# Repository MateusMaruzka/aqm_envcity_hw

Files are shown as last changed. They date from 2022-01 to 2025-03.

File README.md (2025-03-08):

# Air Quality Monitoring Board - EnvCity

## Table of Contents
- [Sensors](#sensors)
- [Powering the board](#powering-the-board)
- [Versions](#versions)
- [Contributing](#contributing)

## Introduction
A detailed explanation of your project, its purpose, and what problem it solves.

## Sensors
Your board supports the following sensors:
- 4 electrochemical sensors
- 1 wind speed sensor
- 1 I2C particulate matter sensor
- 1 DHT11/22 sensor

## Powering the board
Your board supports the following energy sources:
- Solar panel
- Battery
- USB-C

## Versions
There's 2 versions, one it's a 2 layer board and the other it's a 4 layer board (This version could easily be made into a 6 layer board and the fab costs on JLCPCB is the same for 4 or 6 layer boards)

## Contributing
If you have any questions, suggestions, or requests, please send an email to mateusroncaglio@alunos.utfpr.edu.br. We welcome contributions to the project!

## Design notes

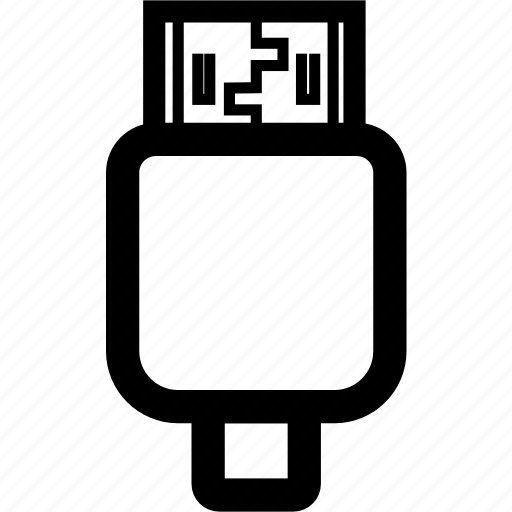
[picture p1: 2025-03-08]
pinout-diagram/img/usb.png

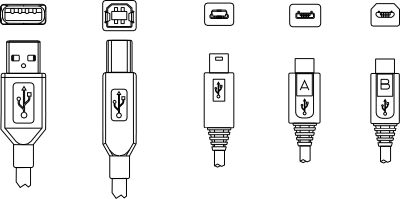
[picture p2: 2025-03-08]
pinout-diagram/img/usbplugs.svg.png

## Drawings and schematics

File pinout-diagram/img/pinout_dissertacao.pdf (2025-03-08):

## GND

## IO21 Data

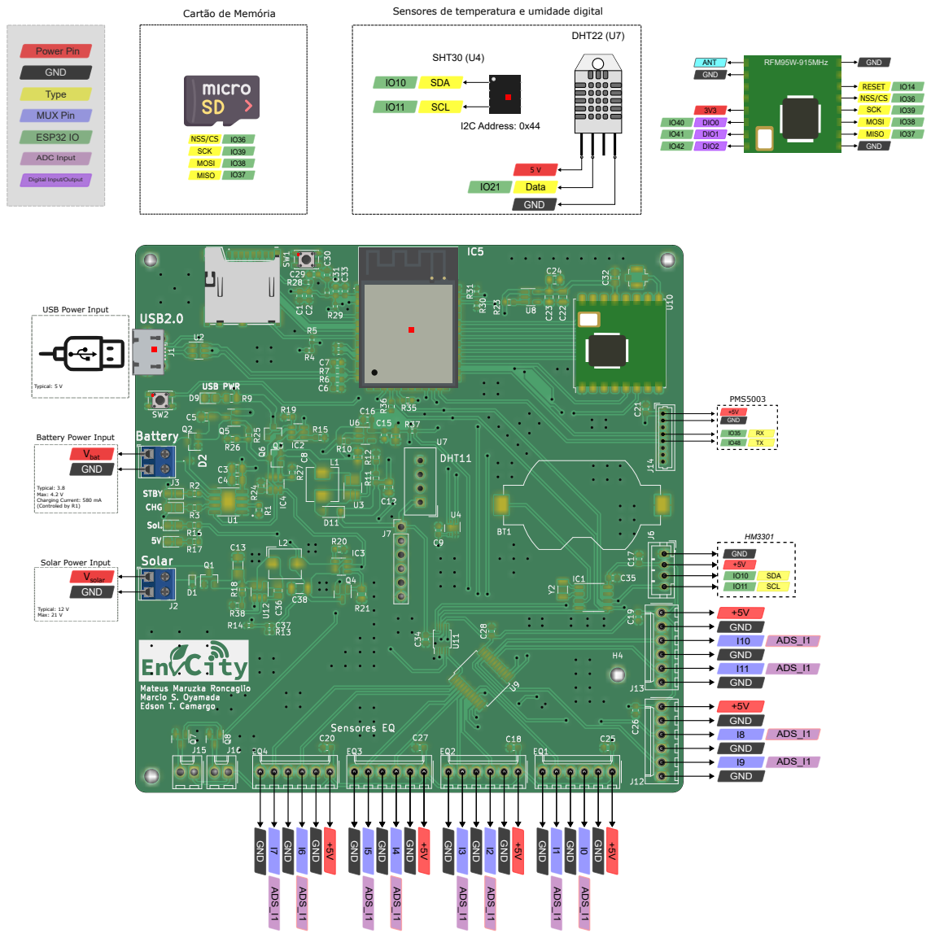
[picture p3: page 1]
GND +5V IO10 IO11; SDA SCL; +5V GND; PMS5003; ADS_I1; I1 ADS_I1; GND; I3 ADS_I1; I10 GND; I8 GND; I5 ADS_I1; I7 ADS_I1; Power Pin; Type; ESP32 IO; MUX Pin; ADC Input; ANT; RFM95W-915MHz; DIO2; DIO1; DIO0; MISO; MOSI; SCK; NSS/CS; RESET; Vbat GND; Vsolar GND; Typical: 12 V Max: 21 V; Typical: 5 V; SHT30 (U4); DHT22 (U7); SDA; I2C Address: 0x44; SCL

Cartão de Memória

Sensores de temperatura e umidade digital

Digital Input/Output

USB Power Input

Battery Power Input

Typical: 3.8
Max: 4.2 V
Charging Current: 580 mA
(Controled by R1)

Solar Power Input

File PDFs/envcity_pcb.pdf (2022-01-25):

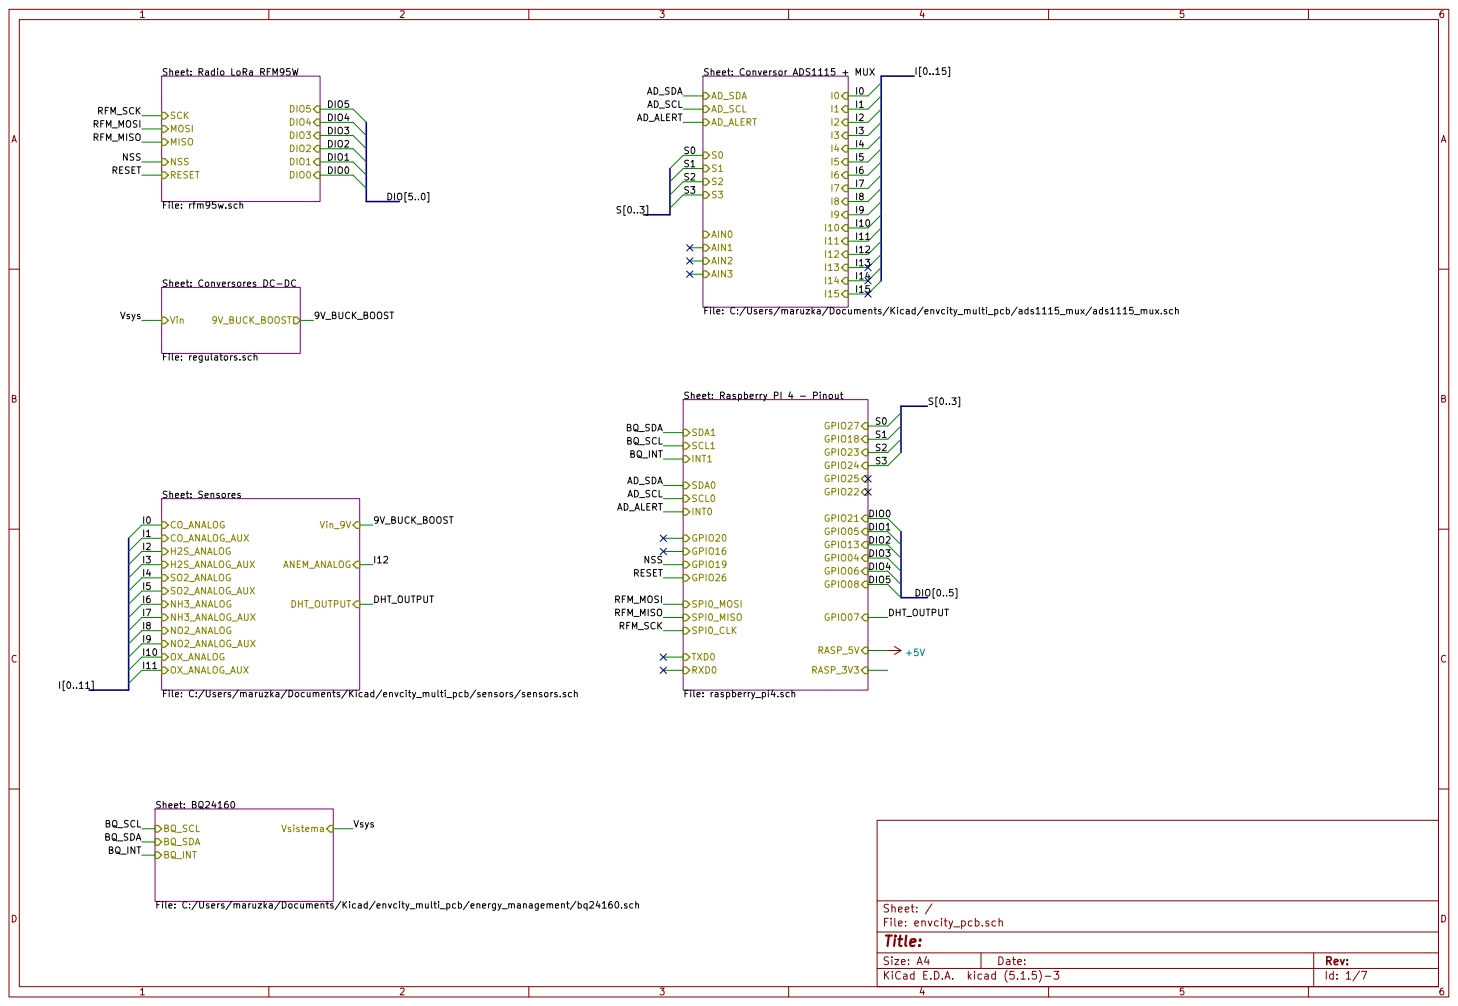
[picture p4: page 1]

AD_SCL AIN0 AIN1 AIN2 AIN3 Sheet: BQ24160 File: C:/Users/maruzka/Documents/Kicad/envcity_multi_pcb/energy_management/bq24160.sch BQ_SCL BQ_SDA

File: C:/Users/maruzka/Documents/Kicad/envcity_multi_pcb/ads1115_mux/ads1115_mux.sch AD_ALERT S0S1S2S3

Sheet: Conversores DC-DC

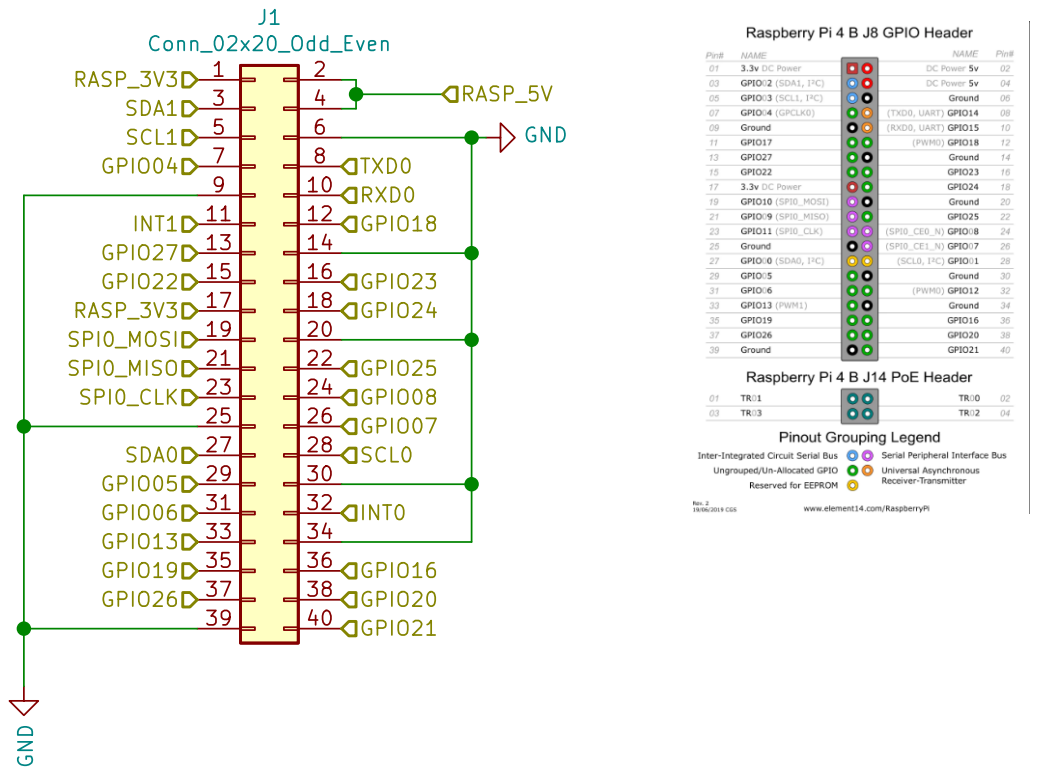
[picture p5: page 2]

Sheet: /Raspberry PI 4 - Pinout/
File: raspberry_pi4.sch
Id: 2/7 Title:

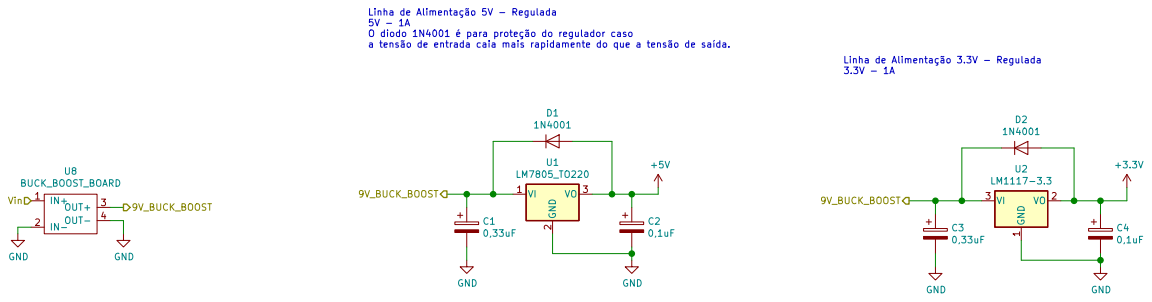
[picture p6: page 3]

Linha de Alimentação 5V - Regulada
5V - 1A O diodo 1N4001 é para proteção do regulador caso

a tensão de entrada caia mais rapidamente do que a tensão de saída.

Linha de Alimentação 3.3V - Regulada

File: regulators.sch Sheet: /Conversores DC-DC/ UNIOESTE/UTFPR

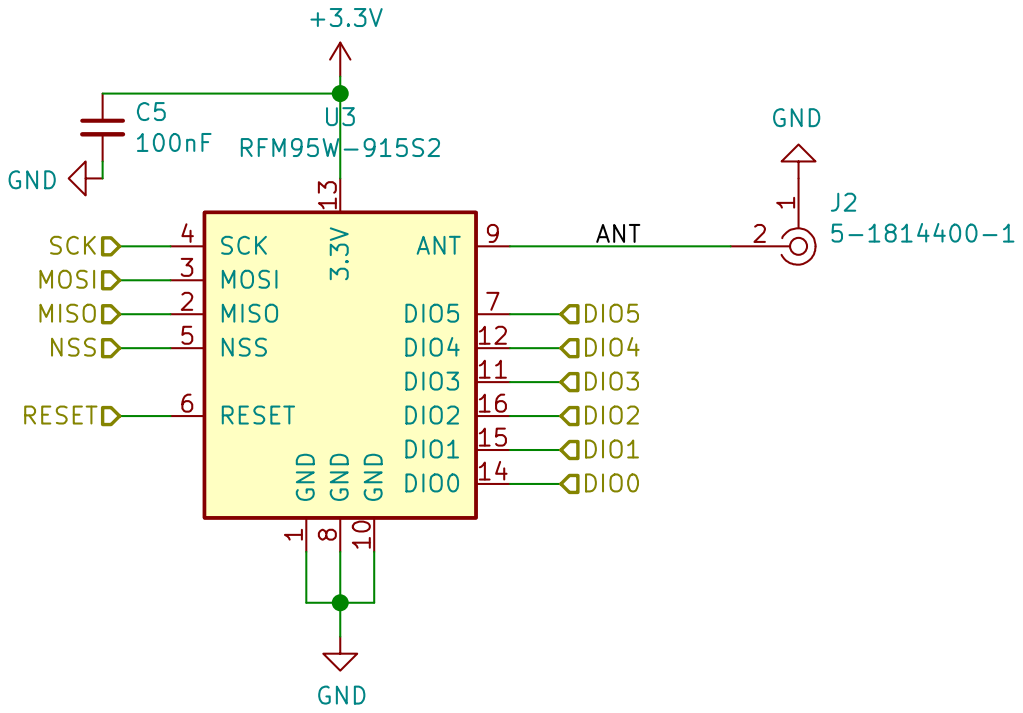
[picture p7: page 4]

8 ANT 9 U3 RFM95W-915S2 RESET DIO5 DIO4 DIO3 NSS MISO MOSI SCK DIO2 DIO1 DIO0 ANT

1 GND 10 DIO3 11 DIO4 12 3.3V 13 DIO0 14 DIO1 15 DIO2 16 MISO 2 MOSI 3 SCK 4 NSS 5 RESET 6 DIO5 7 GND

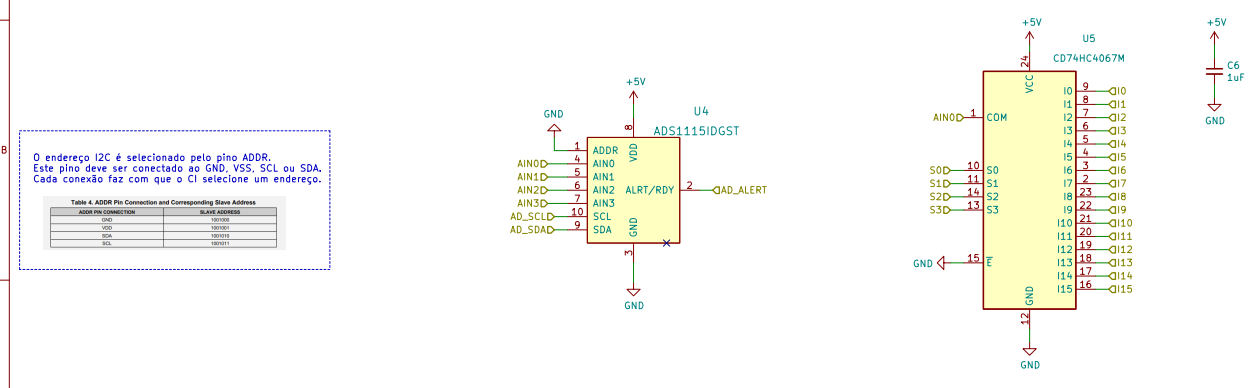
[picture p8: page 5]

I1 AD_SDA O endereço I2C é selecionado pelo pino ADDR.

Este pino deve ser conectado ao GND, VSS, SCL ou SDA.
Cada conexão faz com que o CI selecione um endereço.

File: ads1115_mux.sch Sheet: /Conversor ADS1115 + MUX/ UNIOESTE/UTFPR

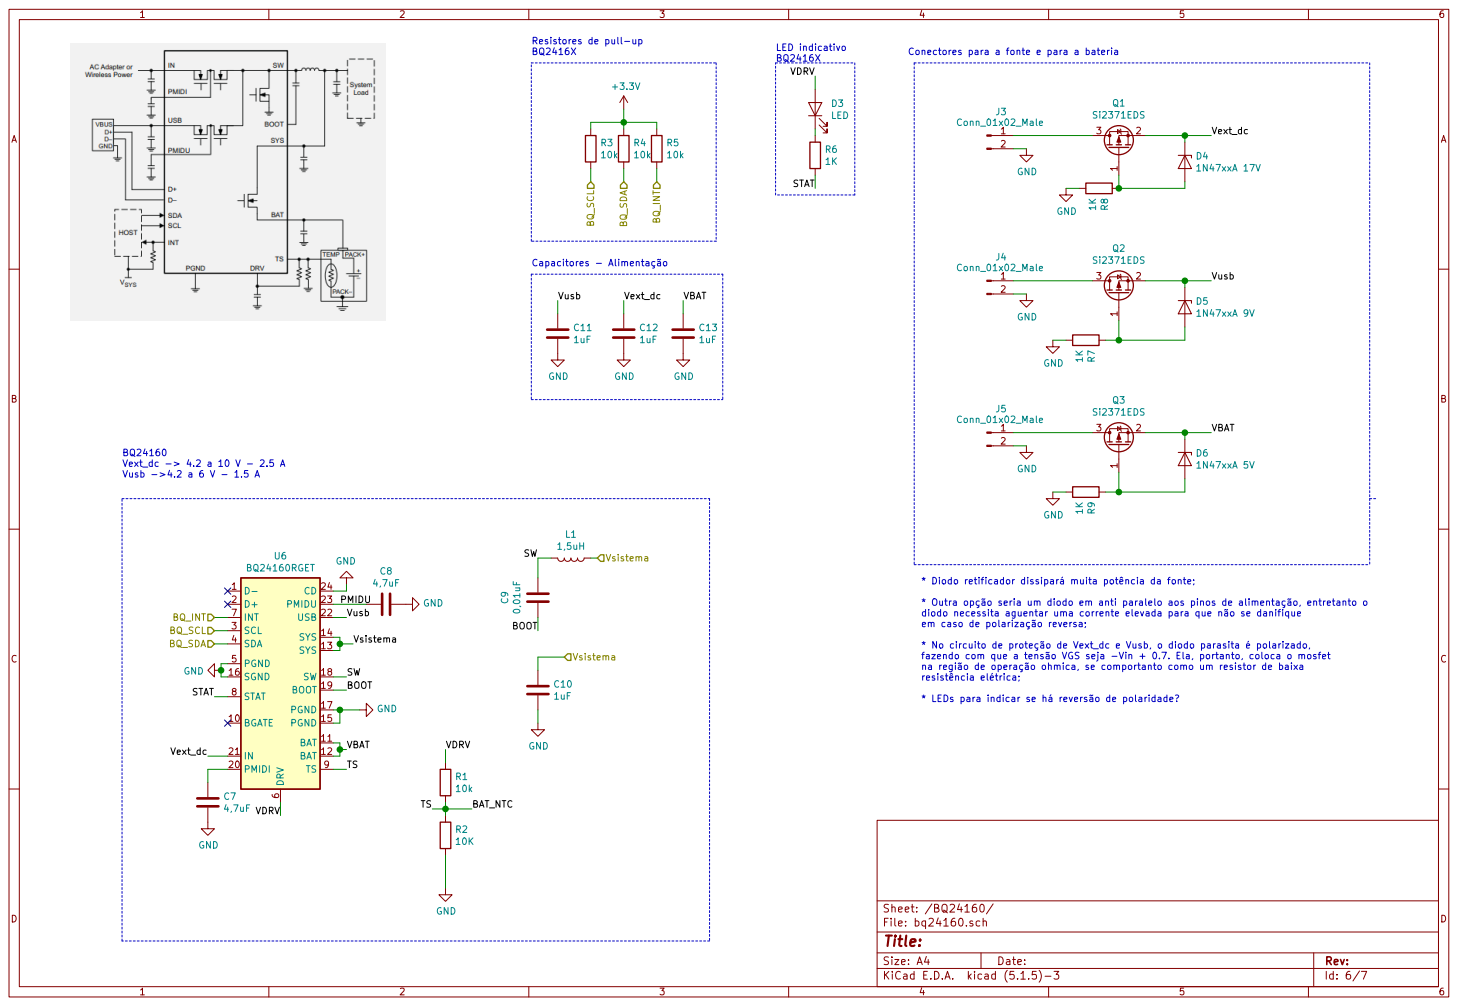
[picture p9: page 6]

Resistores de pull-up BQ2416X

Conectores para a fonte e para a bateria BQ24160 Vext_dc -> 4.2 a 10 V - 2.5 A

* Diodo retificador dissipará muita potência da fonte;

* Outra opção seria um diodo em anti paralelo aos pinos de alimentação, entretanto o
diodo necessita aguentar uma corrente elevada para que não se danifique
em caso de polarização reversa;

* No circuito de proteção de Vext_dc e Vusb, o diodo parasita é polarizado,
fazendo com que a tensão VGS seja -Vin + 0.7. Ela, portanto, coloca o mosfet
na região de operação ohmica, se comportanto como um resistor de baixa resistência elétrica; * LEDs para indicar se há reversão de polaridade?

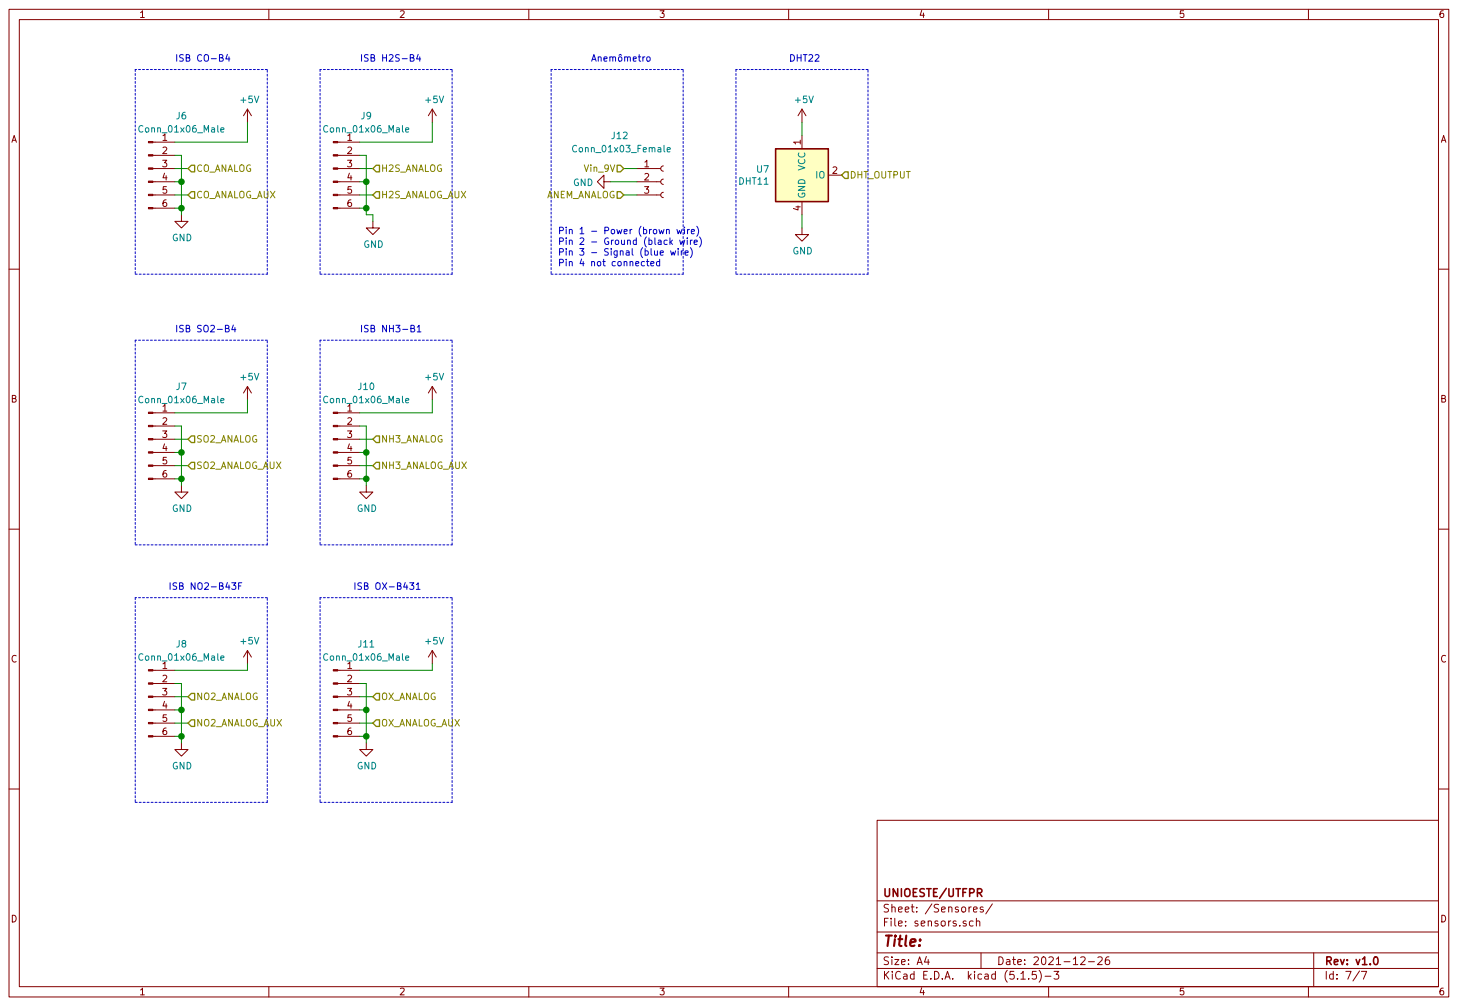
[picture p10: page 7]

Pin 2 - Ground (black wire)
Pin 3 - Signal (blue wire) Pin 4 not connected

Id: 7/7 Title: File: sensors.sch Sheet: /Sensores/ UNIOESTE/UTFPR

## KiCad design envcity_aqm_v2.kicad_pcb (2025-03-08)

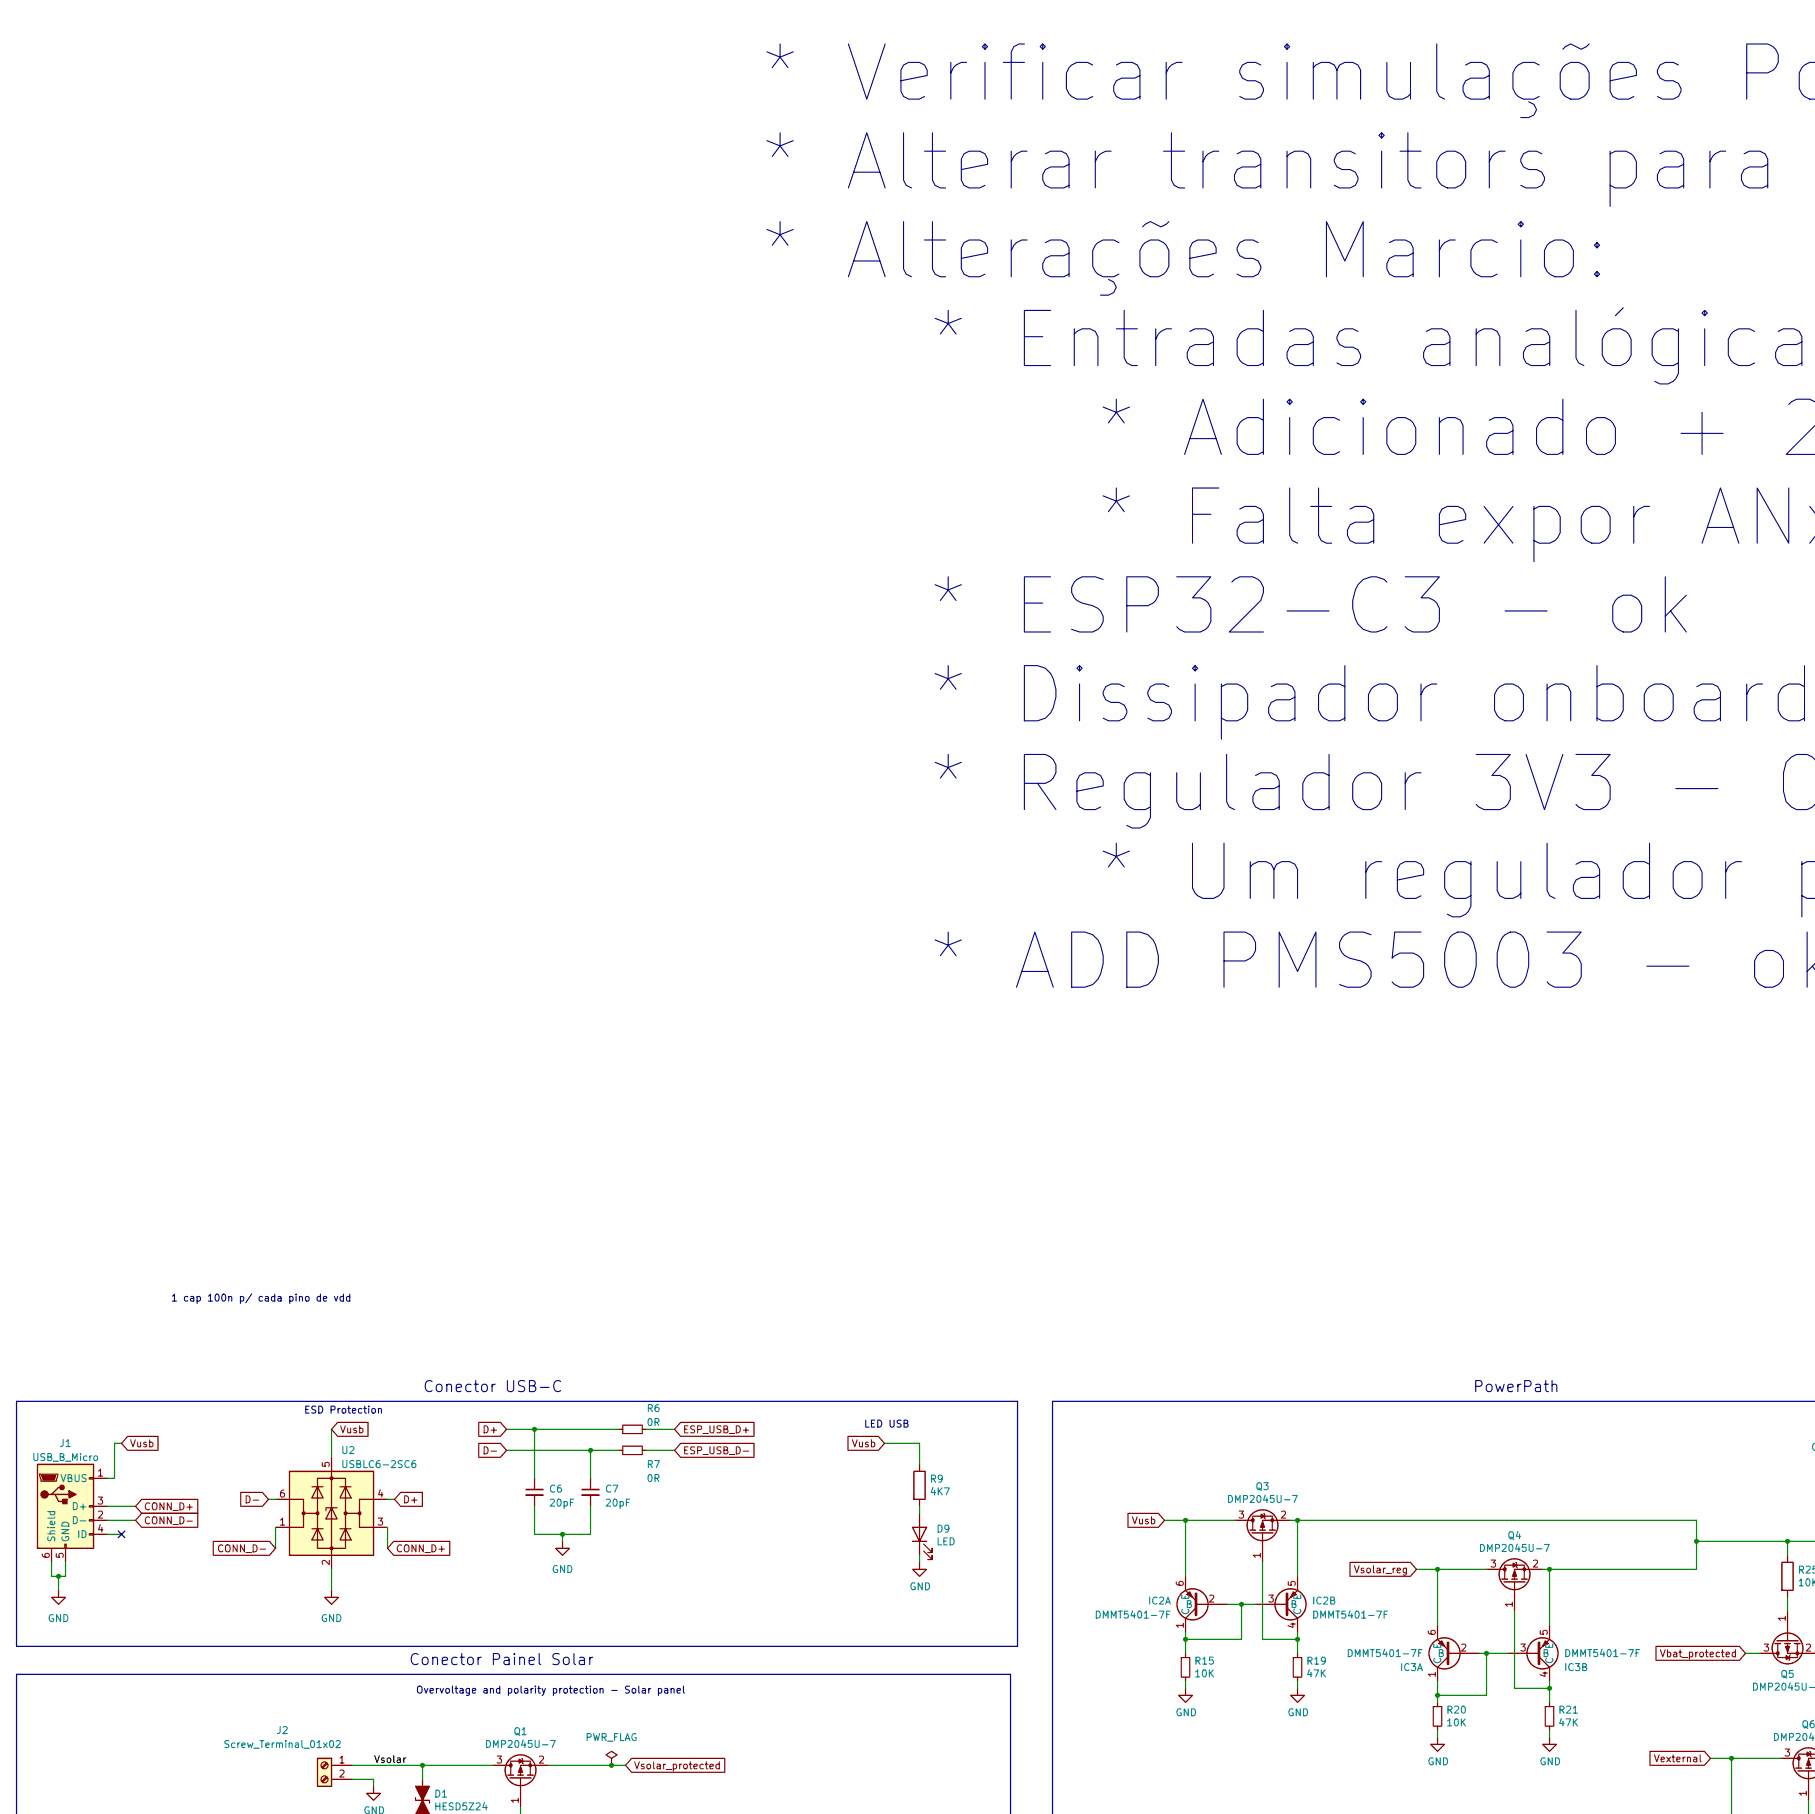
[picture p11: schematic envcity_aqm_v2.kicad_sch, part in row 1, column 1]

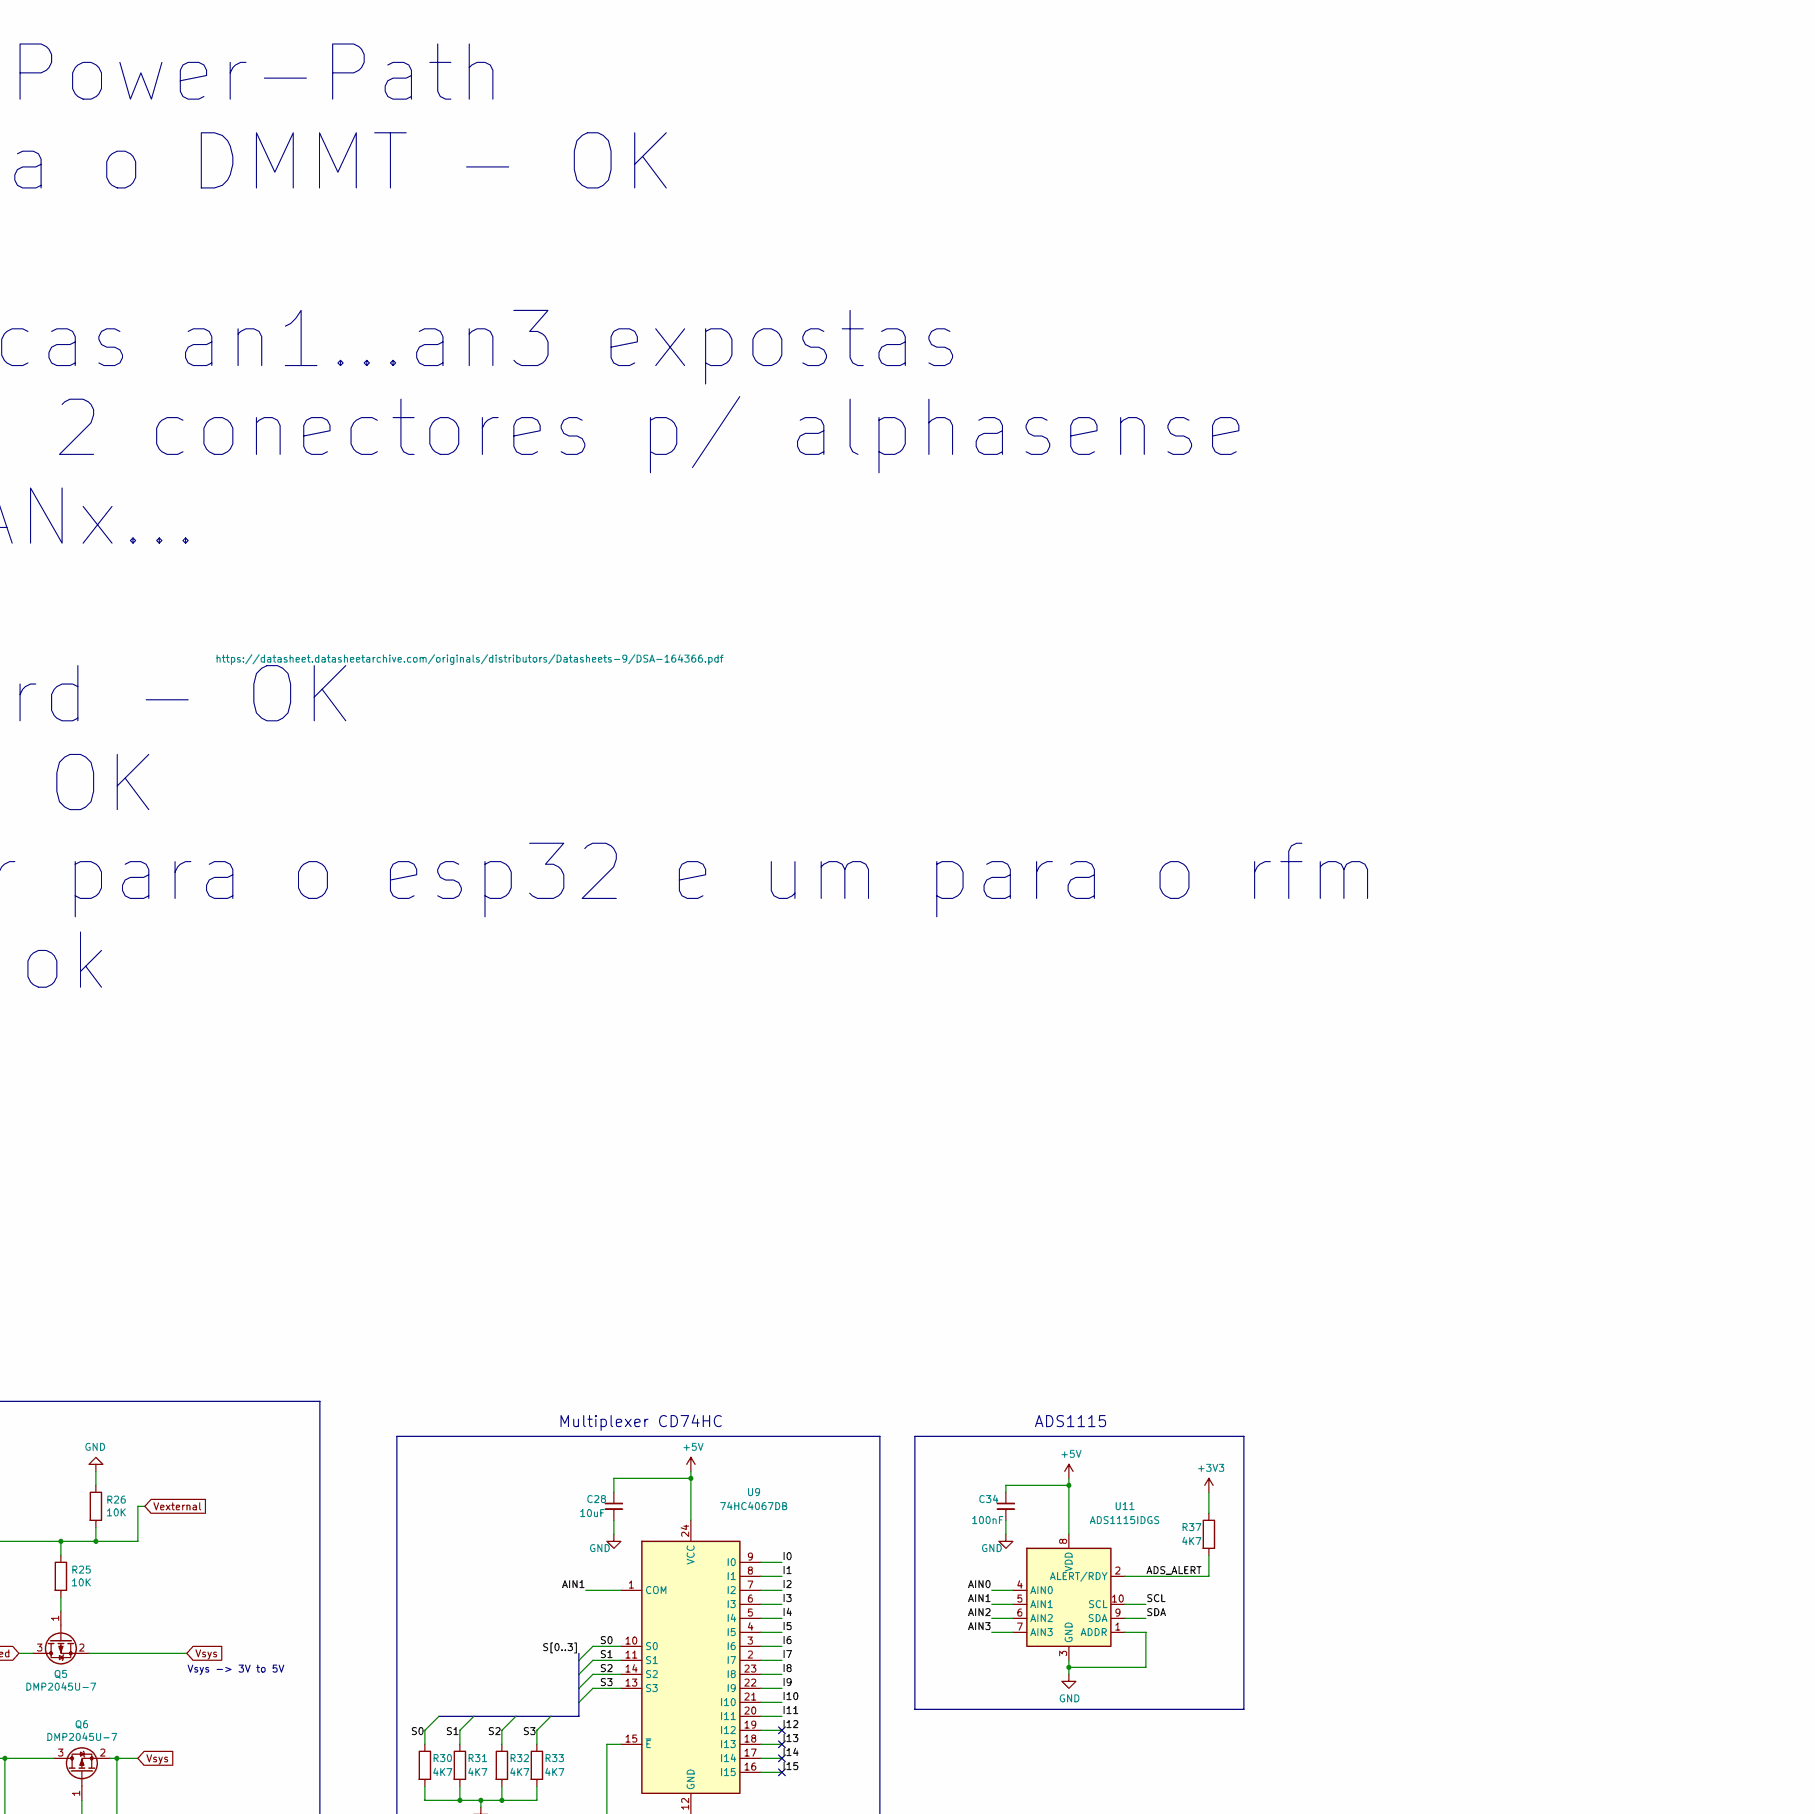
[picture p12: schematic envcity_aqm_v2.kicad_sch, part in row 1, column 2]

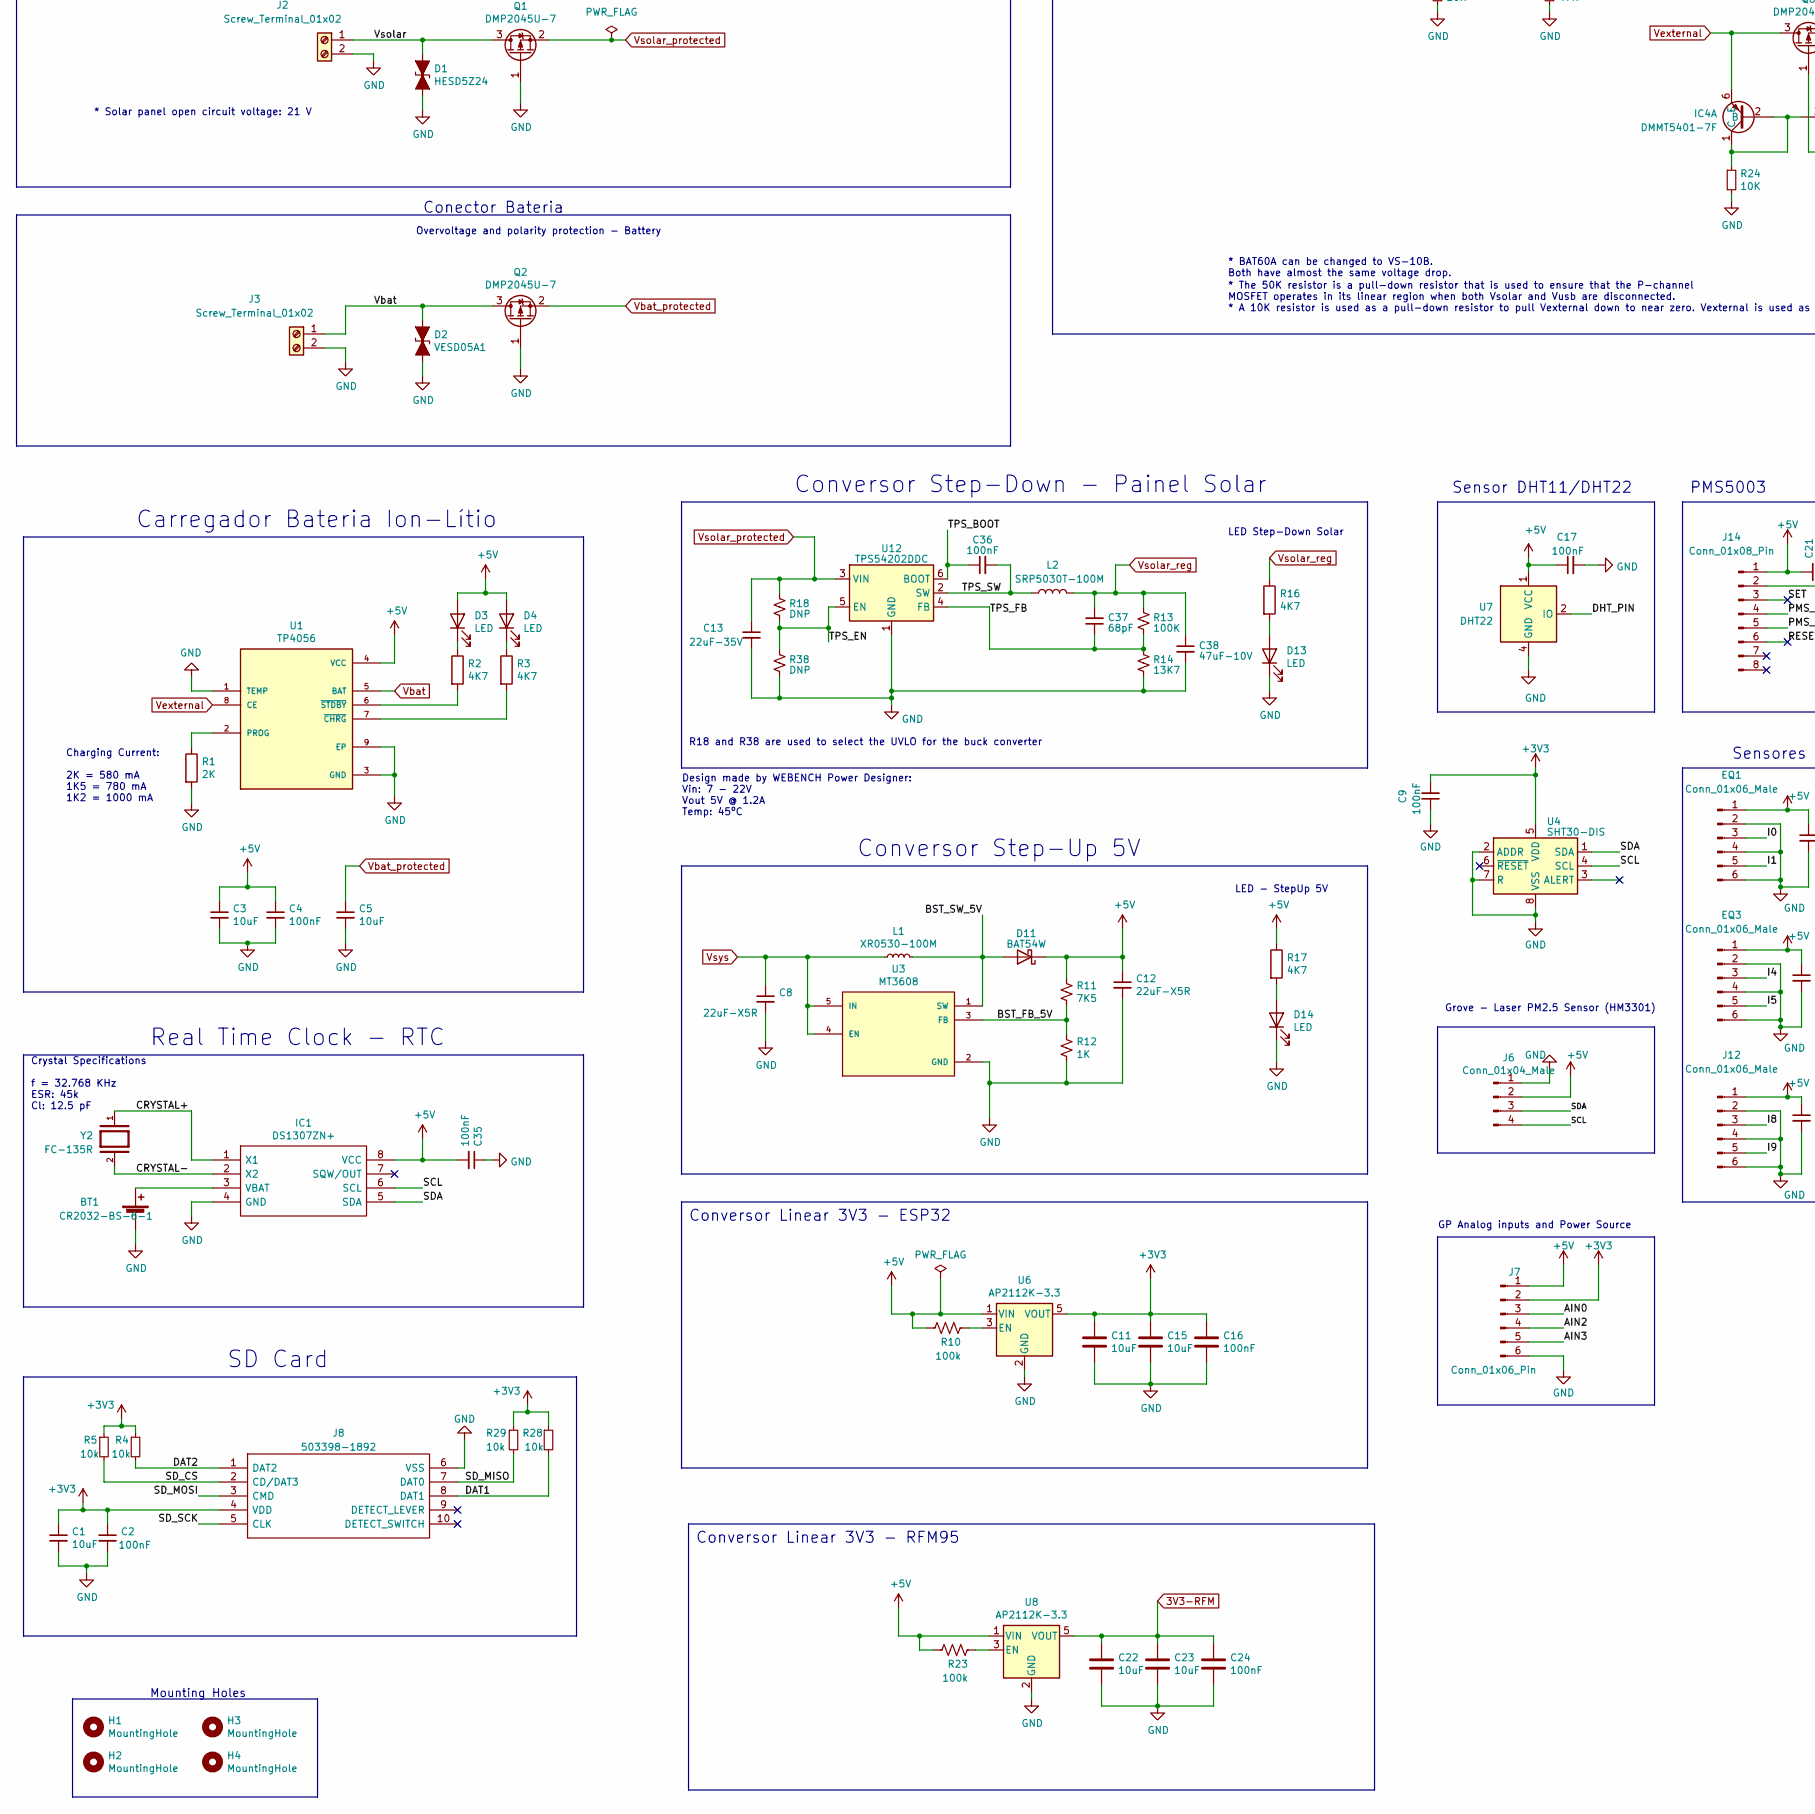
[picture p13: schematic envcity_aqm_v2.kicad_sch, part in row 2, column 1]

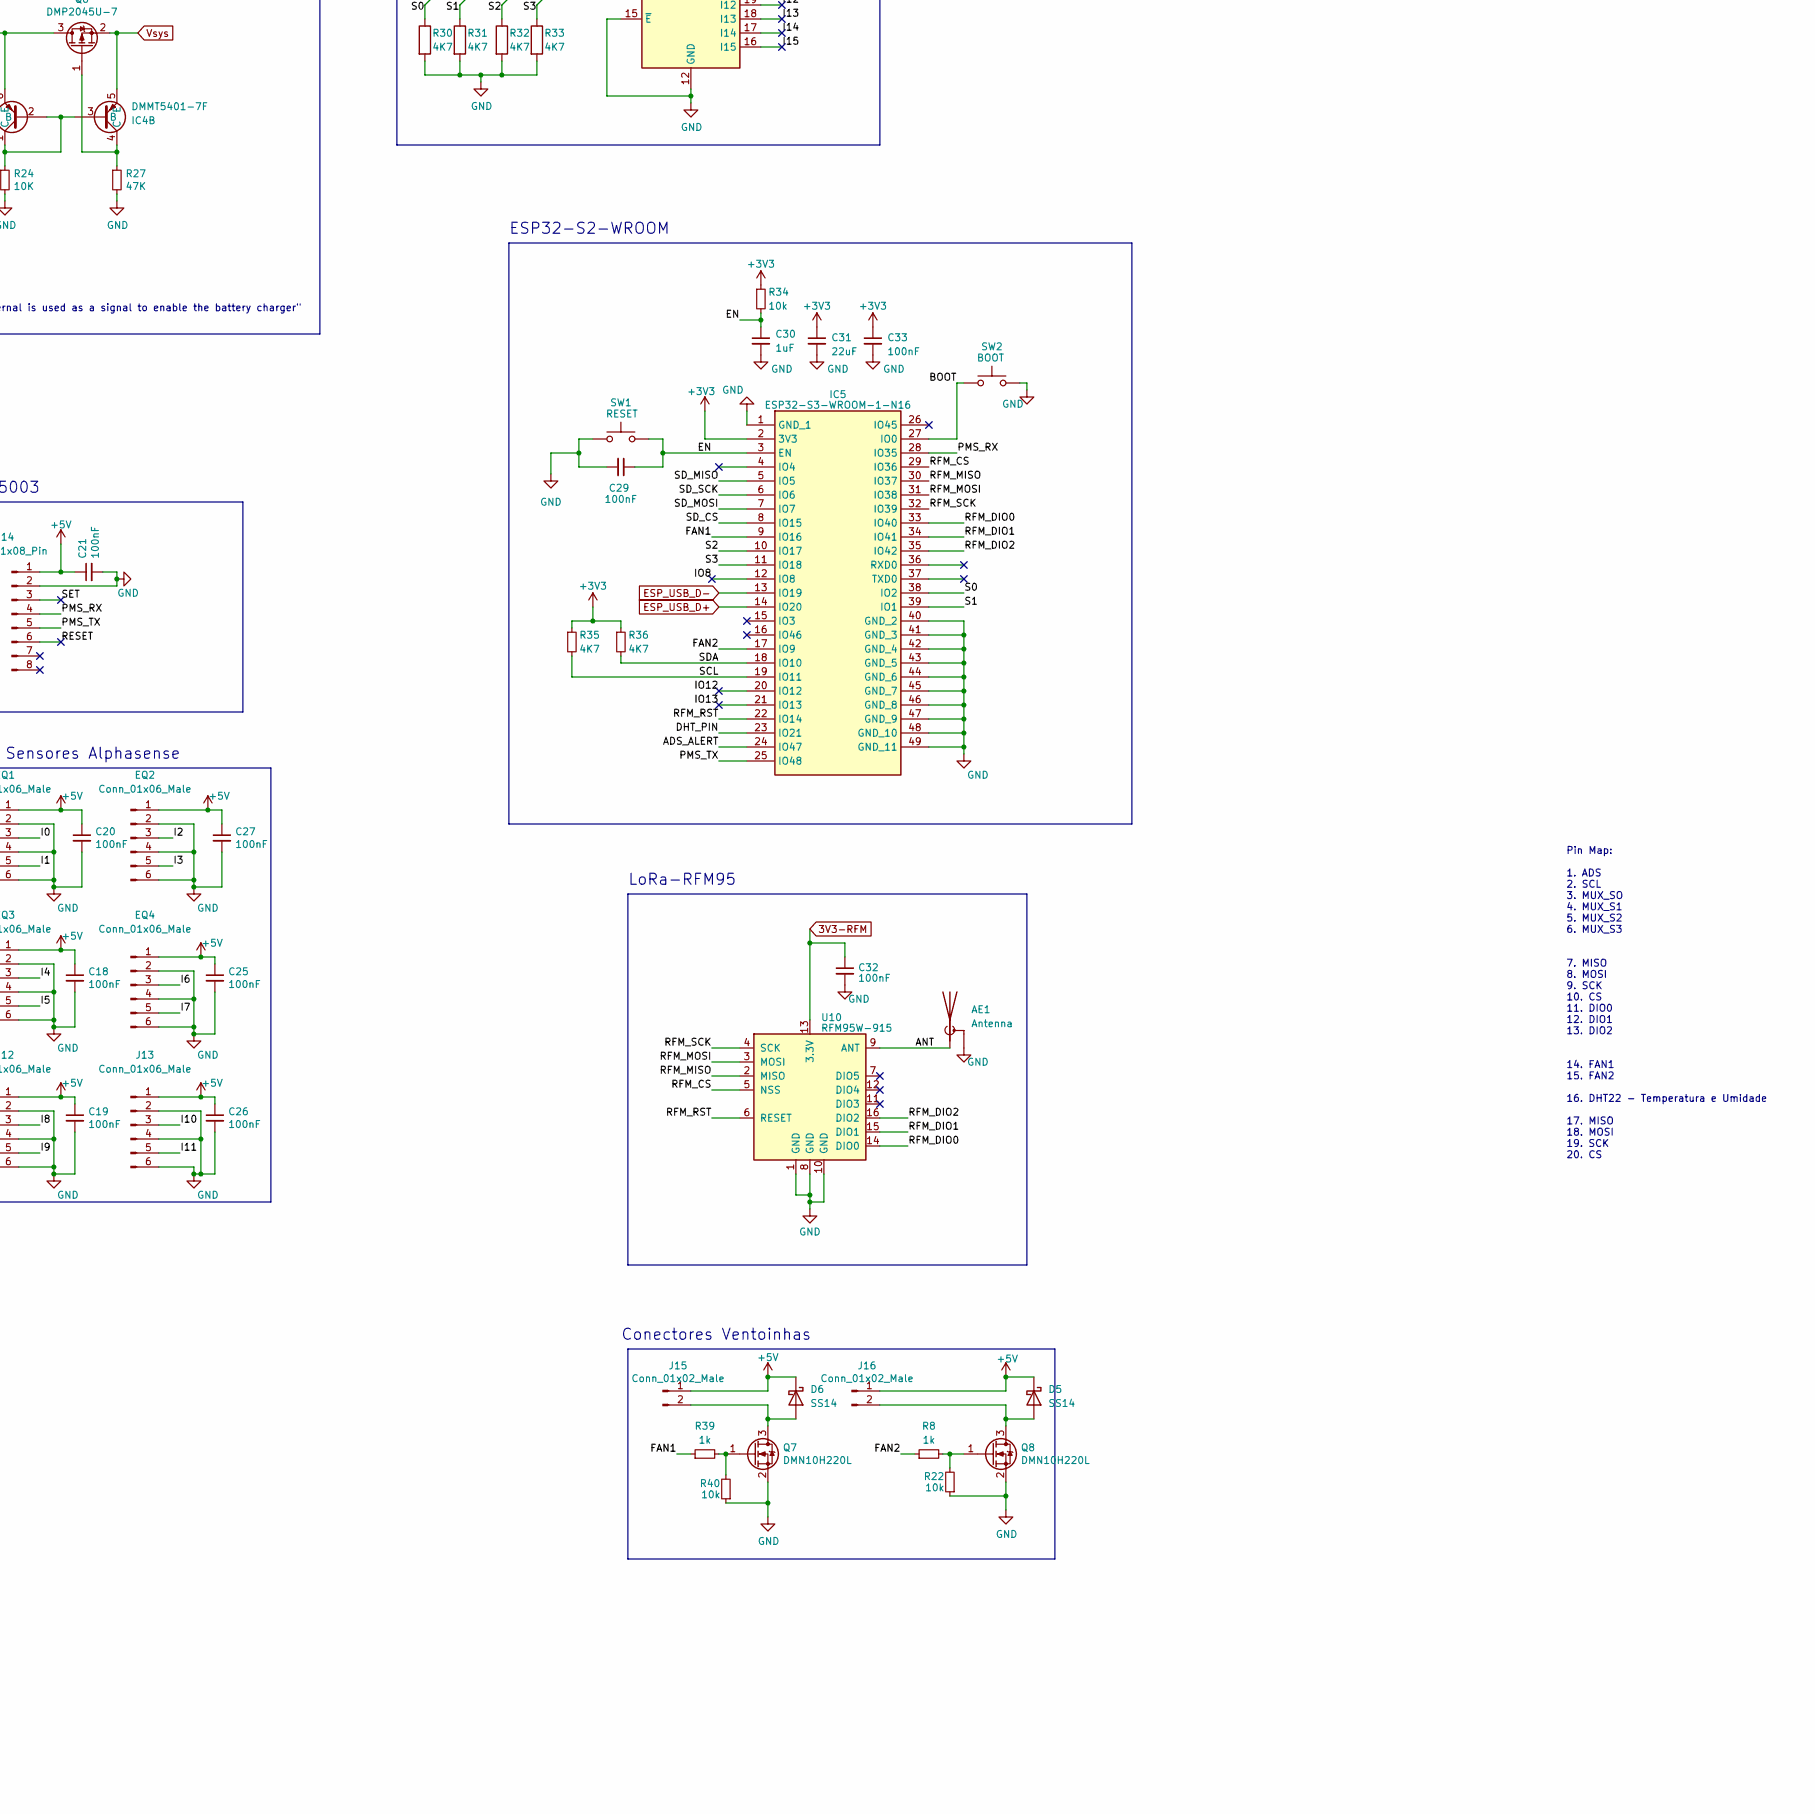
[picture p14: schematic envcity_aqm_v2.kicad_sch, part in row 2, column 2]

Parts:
AE1: Antenna; U.FL_Molex_MCRF_73412-0110_Vertical; LCSC Part # C434806
BT1: CR2032-BS-6-1; BatteryHolder_Keystone_1058_1x2032; LCSC Part # C70377
C1, C15, C28: 10uF; C_0603_1608Metric; LCSC Part # C19702
C2, C9, C16, C17, C18, C19, C20, C21, C25, C26, C27, C29, C33, C34, C35: 100nF; C_0603_1608Metric; LCSC Part # C14663
C3, C5: 10uF; C_0805_2012Metric
C4, C24, C32, C36: 100nF; C_0805_2012Metric; LCSC Part # C14663
C6, C7: 20pF; C_0603_1608Metric
C8, C12: 22uF-X5R; C_0805_2012Metric
C11, C22, C23: 10uF; C_0805_2012Metric; LCSC Part # C19702
C13: 22uF-35V; C_1206_3216Metric; Part # C3216X5R1V226M160AC
C30: 1uF; C_0603_1608Metric
C31: 22uF; C_0603_1608Metric
C37: 68pF; C_0402_1005Metric
C38: 47uF-10V; C_1206_3216Metric; Part # GRM32ER71A476KE15L
D1: HESD5Z24; D_SOD-523; LCSC Part # C3002989
D2: VESD05A1; PESD24VS1ULQZ; LCSC Part # C2844735
D3, D4, D9, D13, D14: LED; LED_0805_2012Metric_Pad1.15x1.40mm_HandSolder
D5, D6: SS14; D_SMA
D11: BAT54W; D_SOD-123; LCSC Part # C915628
EQ1, EQ2, EQ3, EQ4: Conn_01x06_Male; Molex_KK-254_AE-6410-06A_1x06_P2.54mm_Vertical; LCSC Part # C2847672
H1: MountingHole; MountingHole_2.2mm_M2
H2, H3, H4: MountingHole; MountingHole_2.5mm
IC1: DS1307ZN+; SOP-8_3.9x4.9mm_P1.27mm; Mouser Part Number 700-DS1307ZN
IC2, IC3, IC4: DMMT5401-7F; SOT-23-6; Mouser Part Number 621-DMMT5401-7-F
IC5: ESP32-S3-WROOM-1-N16; ESP32S3WROOM1N16; Mouser Part Number 356-ESP32S3WROOM1N16
J1: USB_B_Micro; USB_Micro-B_Molex-105017-0001; JLCPCB Part # C136000
J2, J3: Screw_Terminal_01x02; TerminalBlock_TE_282834-2_1x02_P2.54mm_Horizontal; LCSC Part # C3029316
J6: Conn_01x04_Male; JST_PH_B4B-PH-K_1x04_P2.00mm_Vertical; LCSC Part # C2764213
J7: Conn_01x06_Pin; PinHeader_1x06_P2.54mm_Vertical
J8: 503398-1892; Mouser Part Number 538-503398-1892
J12, J13: Conn_01x06_Male; Molex_KK-254_AE-6410-06A_1x06_P2.54mm_Vertical; LCSC Part # C2847672
J14: Conn_01x08_Pin; Molex_PicoBlade_53047-0810_1x08_P1.25mm_Vertical; JLCPCB Part # C240845
J15: Conn_01x02_Male; Molex_KK-254_AE-6410-02A_1x02_P2.54mm_Vertical; Mfr. Part # 22112022; LCSC Part # C509147
J16: Conn_01x02_Male; Molex_KK-254_AE-6410-02A_1x02_P2.54mm_Vertical; LCSC Part # C509147
L1: XR0530-100M; L_Chilisin_BMRA00050530; LCSC Part # C5307602
L2: SRP5030T-100M; L_Bourns_SRP5030T; Part # SRP5030T-100M; LCSC Part # C189932
Q1, Q2, Q3, Q4, Q5, Q6: DMP2045U-7; SOT-23; LCSC Part # C459541
Q7, Q8: DMN10H220L; SOT-23; LCSC Part # C5122013
R1: 2K; R_0603_1608Metric
R2, R3, R16, R17, R35, R36: 4K7; R_0603_1608Metric; LCSC Part # C23162
R4, R5, R28, R29, R34: 10k; R_0402_1005Metric; LCSC Part # C25744
R6, R7: 0R; R_0603_1608Metric
R8, R39: 1k; R_0805_2012Metric
R9: 4K7; R_0805_2012Metric
R10, R23: 100k; R_0603_1608Metric; LCSC Part # C25804
R11: 7K5; R_0603_1608Metric
R12: 1K; R_0603_1608Metric
R13: 100K; R_0402_1005Metric
R14: 13K7; R_0402_1005Metric
R15, R20, R24, R25, R26: 10K; R_0603_1608Metric; LCSC Part # C25804
R18, R38: DNP; R_0603_1608Metric
R19, R27: 47K; R_0603_1608Metric
R21: 47K; R_0805_2012Metric
R22, R40: 10k; R_0805_2012Metric
R30, R31, R32, R33, R37: 4K7; R_0402_1005Metric; LCSC Part # C25900
SW1: RESET; SW_SPST_PTS810; JLCPCB Part # C221897
SW2: BOOT; SW_SPST_PTS810; JLCPCB Part # C221897
U1: TP4056; SOP127P600X175-9N; LCSC Part # C382139
U2: USBLC6-2SC6; SOT-23-6; LCSC Part # C7519
U3: MT3608; SOT-23-6_Handsoldering; PARTREV 1.0; JLCPCB Part # C84817
U4: SHT30-DIS; Sensirion_DFN-8-1EP_2.5x2.5mm_P0.5mm_EP1.1x1.7mm; JLCPCB Part # C2687423
U6, U8: AP2112K-3.3; SOT-23-5; LCSC Part # C51118
U7: DHT22; Aosong_DHT11_5.5x12.0_P2.54mm
U9: 74HC4067DB; SSOP-24_5.3x8.2mm_P0.65mm; LCSC Part # C97702
U10: RFM95W-915; HOPERF_RFM9XW_SMD; LCSC Part # C2844473
U11: ADS1115IDGS; TSSOP-10_3x3mm_P0.5mm; JLCPCB Part # C37593
U12: TPS54202DDC; SOT-23-6
Y2: FC-135R; Crystal_SMD_3215-2Pin_3.2x1.5mm; JLCPCB Part # C94276

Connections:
3V3-RFM: C22.1, C23.1, C24.1, C32.1, U8.5 (VOUT), U10.13 (3.3V)
+3V3: C1.1, C2.1, C9.2, C11.1, C15.1, C16.1, C31.1, C33.1, IC5.2 (3V3), J7.2, J8.4 (VDD), R4.1, R5.1, R28.1, R29.1, R34.1, R35.1, R36.1, R37.1, U4.5 (VDD), U6.5 (VOUT)
+5V: C3.1, C4.1, C12.1, C17.1, C18.1, C19.1, C20.1, C21.1, C25.1, C26.1, C27.1, C28.1, C34.1, C35.2, D3.2 (A), D4.2 (A), D5.1 (K), D6.1 (K), D11.1 (K), EQ1.1, EQ2.1, EQ3.1, EQ4.1, IC1.8 (VCC), J6.2, J7.1, J12.1, J13.1, J14.1, J15.1, J16.1, R10.1, R11.1, R17.1, R23.1, U1.4 (VCC), U6.1 (VIN), U7.1 (VCC), U8.1 (VIN), U9.24 (VCC), U11.8 (VDD)
/ADS_ALERT: IC5.24 (IO47), R37.2, U11.2 (ALERT/RDY)
/AIN0: J7.3, U11.4 (AIN0)
/AIN1: U9.1 (COM), U11.5 (AIN1)
/AIN2: J7.4, U11.6 (AIN2)
/AIN3: J7.5, U11.7 (AIN3)
/ANT: AE1.1 (A), U10.9 (ANT)
/BOOT: IC5.27 (IO0), SW2.1
/BST_FB_5V: R11.2, R12.1, U3.3 (FB)
/BST_SW_5V: D11.2 (A), L1.2, U3.1 (SW)
/CRYSTAL+: IC1.1 (X1), Y2.1
/CRYSTAL-: IC1.2 (X2), Y2.2
/DAT1: J8.8 (DAT1), R28.2
/DAT2: J8.1 (DAT2), R4.2
/DHT_PIN: IC5.23 (IO21), U7.2 (IO)
/EN: C29.1, C30.1, IC5.3 (EN), R34.2, SW1.2
/FAN1: IC5.9 (IO16), R39.1
/FAN2: IC5.17 (IO9), R8.1
/I0: EQ1.3, U9.9 (I0)
/I1: EQ1.5, U9.8 (I1)
/I2: EQ2.3, U9.7 (I2)
/I3: EQ2.5, U9.6 (I3)
/I4: EQ3.3, U9.5 (I4)
/I5: EQ3.5, U9.4 (I5)
/I6: EQ4.3, U9.3 (I6)
/I7: EQ4.5, U9.2 (I7)
/I8: J12.3, U9.23 (I8)
/I9: J12.5, U9.22 (I9)
/I10: J13.3, U9.21 (I10)
/I11: J13.5, U9.20 (I11)
/I12: U9.19 (I12)
/I13: U9.18 (I13)
/I14: U9.17 (I14)
/I15: U9.16 (I15)
/IO8: IC5.12 (IO8)
/IO12: IC5.20 (IO12)
/IO13: IC5.21 (IO13)
/PMS_RX: IC5.28 (IO35), J14.4
/PMS_TX: IC5.25 (IO48), J14.5
/RESET: J14.6
/RFM_CS: IC5.29 (IO36), U10.5 (NSS)
/RFM_DIO0: IC5.33 (IO40), U10.14 (DIO0)
/RFM_DIO1: IC5.34 (IO41), U10.15 (DIO1)
/RFM_DIO2: IC5.35 (IO42), U10.16 (DIO2)
/RFM_MISO: IC5.30 (IO37), U10.2 (MISO)
/RFM_MOSI: IC5.31 (IO38), U10.3 (MOSI)
/RFM_RST: IC5.22 (IO14), U10.6 (RESET)
/RFM_SCK: IC5.32 (IO39), U10.4 (SCK)
/S0: IC5.38 (IO2), R30.1, U9.10 (S0)
/S1: IC5.39 (IO1), R31.1, U9.11 (S1)
/S2: IC5.10 (IO17), R32.1, U9.14 (S2)
/S3: IC5.11 (IO18), R33.1, U9.13 (S3)
/SCL: IC1.6 (SCL), IC5.19 (IO11), J6.4, R35.2, U4.4 (SCL), U11.10 (SCL)
/SDA: IC1.5 (SDA), IC5.18 (IO10), J6.3, R36.2, U4.1 (SDA), U11.9 (SDA)
/SD_CS: IC5.8 (IO15), J8.2 (CD/DAT3), R5.2
/SD_MISO: IC5.5 (IO5), J8.7 (DAT0), R29.2
/SD_MOSI: IC5.7 (IO7), J8.3 (CMD)
/SD_SCK: IC5.6 (IO6), J8.5 (CLK)
/SET: J14.3
/TPS_BOOT: C36.1, U12.6 (BOOT)
/TPS_EN: R18.2, R38.1, U12.5 (EN)
/TPS_FB: C37.1, R13.2, R14.1, U12.4 (FB)
/TPS_SW: C36.2, L2.1, U12.2 (SW)
/Vsolar: D1.1 (A1), J2.1, Q1.3 (D)
CONN_D+: J1.3 (D+), U2.3 (I/O2)
CONN_D-: J1.2 (D-), U2.1 (I/O1)
D+: C6.1, R6.1, U2.4 (I/O2)
D-: C7.1, R7.1, U2.6 (I/O1)
ESP_USB_D+: IC5.14 (IO20), R6.2
ESP_USB_D-: IC5.13 (IO19), R7.2
GND: AE1.2 (Shield), BT1.2 (-), C1.2, C2.2, C3.2, C4.2, C5.2, C6.2, C7.2, C8.2, C9.1, C11.2, C12.2, C13.2, C15.2, C16.2, C17.2, C18.2, C19.2, C20.2, C21.2, C22.2, C23.2, C24.2, C25.2, C26.2, C27.2, C28.2, C29.2, C30.2, C31.2, C32.2, C33.2, C34.2, C35.1, C38.2, D1.2 (A2), D2.2 (A2), D9.1 (K), D13.1 (K), D14.1 (K), EQ1.2, EQ1.4, EQ1.6, EQ2.2, EQ2.4, EQ2.6, EQ3.2, EQ3.4, EQ3.6, EQ4.2, EQ4.4, EQ4.6, IC1.4 (GND), IC5.1 (GND_1), IC5.40 (GND_2), IC5.41 (GND_3), IC5.42 (GND_4), IC5.43 (GND_5), IC5.44 (GND_6), IC5.45 (GND_7), IC5.46 (GND_8), IC5.47 (GND_9), IC5.48 (GND_10), IC5.49 (GND_11), J1.5 (GND), J1.6 (Shield), J2.2, J3.2, J6.1, J7.6, J8.6 (VSS), J12.2, J12.4, J12.6, J13.2, J13.4, J13.6, J14.2, Q1.1 (G), Q2.1 (G), Q7.2 (S), Q8.2 (S), R1.2, R12.2, R14.2, R15.2, R19.2, R20.2, R21.2, R22.1, R24.2, R26.1, R27.2, R30.2, R31.2, R32.2, R33.2, R38.2, R40.1, SW1.1, SW2.2, U1.1 (TEMP), U1.3 (GND), U1.9 (EP), U2.2 (GND), U3.2 (GND), U4.2 (ADDR), U4.7 (R), U4.8 (VSS), U4.9 (VSS), U6.2 (GND), U7.4 (GND), U8.2 (GND), U9.12 (GND), U9.15 (~E), U10.1 (GND), U10.8 (GND), U10.10 (GND), U11.1 (ADDR), U11.3 (GND), U12.1 (GND)
unnamed: BT1.1 (+), IC1.3 (VBAT)
unnamed: D3.1 (K), R2.1
unnamed: D4.1 (K), R3.1
unnamed: D5.2 (A), J16.2, Q8.3 (D)
unnamed: D6.2 (A), J15.2, Q7.3 (D)
unnamed: D9.2 (A), R9.2
unnamed: D13.2 (A), R16.2
unnamed: D14.2 (A), R17.2
unnamed: IC2.1 (C), IC2.2 (B), IC2.3 (B), R15.1
unnamed: IC2.4 (C), Q3.1 (G), R19.1
unnamed: IC3.1 (C), IC3.2 (B), IC3.3 (B), R20.1
unnamed: IC3.4 (C), Q4.1 (G), R21.1
unnamed: IC4.1 (C), IC4.2 (B), IC4.3 (B), R24.1
unnamed: IC4.4 (C), Q6.1 (G), R27.1
unnamed: Q5.1 (G), R25.2
unnamed: Q7.1 (G), R39.2, R40.2
unnamed: Q8.1 (G), R8.2, R22.2
unnamed: R1.1, U1.2 (PROG)
unnamed: R3.2, U1.7 (~CHRG)
unnamed: R2.2, U1.6 (~STDBY)
unnamed: R10.2, U6.3 (EN)
unnamed: R23.2, U8.3 (EN)
Vbat: D2.1 (A1), J3.1, Q2.3 (D), U1.5 (BAT)
Vbat_protected: C5.1, Q2.2 (S), Q5.3 (D)
Vexternal: IC2.5 (E), IC3.5 (E), IC4.6 (E), Q3.2 (S), Q4.2 (S), Q6.3 (D), R25.1, R26.2, U1.8 (CE)
Vsolar_protected: C13.1, Q1.2 (S), R18.1, U12.3 (VIN)
Vsolar_reg: C37.2, C38.1, IC3.6 (E), L2.2, Q4.3 (D), R13.1, R16.1
Vsys: C8.1, IC4.5 (E), L1.1, Q5.2 (S), Q6.2 (S), U3.4 (EN), U3.5 (IN)
Vusb: IC2.6 (E), J1.1 (VBUS), Q3.3 (D), R9.1, U2.5 (VBUS)

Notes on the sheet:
Conector Bateria
* The 50K resistor is a pull-down resistor that is used to ensure that the P-channel MOSFET operates in its linear region when both Vsolar and Vusb are disconnected. * A 10K resistor is used as a pull-down resistor to pull Vexternal down to near zero. Vexternal is used as a signal to enable the bat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
Sensor DHT11/DHT22
LED Step-Down Solar
Conversor Linear 3V3 - RFM95
Pin Map: 1. ADS 2. SCL 3. MUX_SO 4. MUX_S1 5. MUX_S2 6. MUX_S3 7. MISO 8. MOSI 9. SCK 10. CS 11. DIO0 12. DIO1 13. DIO2 14. FAN1 15. FAN2 16. DHT22 - Temperatura e Umidade 17. MISO 18. MOSI 19. SCK 20. CS
Overvoltage and polarity protection - Solar panel
ESD Protection
Overvoltage and polarity protection - Battery
Vsys -> 3V to 5V
Real Time Clock - RTC
Mounting Holes
PMS5003
* BAT60A can be changed to VS-10B. Both have almost the same voltage drop.
Conversor Linear 3V3 - ESP32
Conector Painel Solar
Design made by WEBENCH Power Designer: Vin: 7 - 22V Vout 5V @ 1.2A Temp: 45ºC
Charging Current: 2K = 580 mA 1K5 = 780 mA 1K2 = 1000 mA
Conector USB-C
LED USB
LED - StepUp 5V
SD Card
ADS1115
* Solar panel open circuit voltage: 21 V
Conversor Step-Down - Painel Solar
Multiplexer CD74HC
* Verificar simulações Power-Path * Alterar transitors para o DMMT - OK * Alterações Marcio: * Entradas analógicas an1...an3 expostas * Adicionado + 2 conectores p/ alphasense * Falta expor ANx... * ESP32-C3 - ok * Dissipador onboard - OK * Regulador 3V3 - OK * Um regulador para o esp32 e um para o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
PowerPath
Conversor Step-Up 5V
Carregador Bateria Ion-Lítio
ESP32-S2-WROOM
Grove - Laser PM2.5 Sensor (HM3301)
GP Analog inputs and Power Source
LoRa-RFM95
1 cap 100n p/ cada pino de vdd
Crystal Specifications f = 32.768 KHz ESR: 45k Cl: 12.5 pF
R18 and R38 are used to select the UVLO for the buck converter
Conectores Ventoinhas
Sensores Alphasense

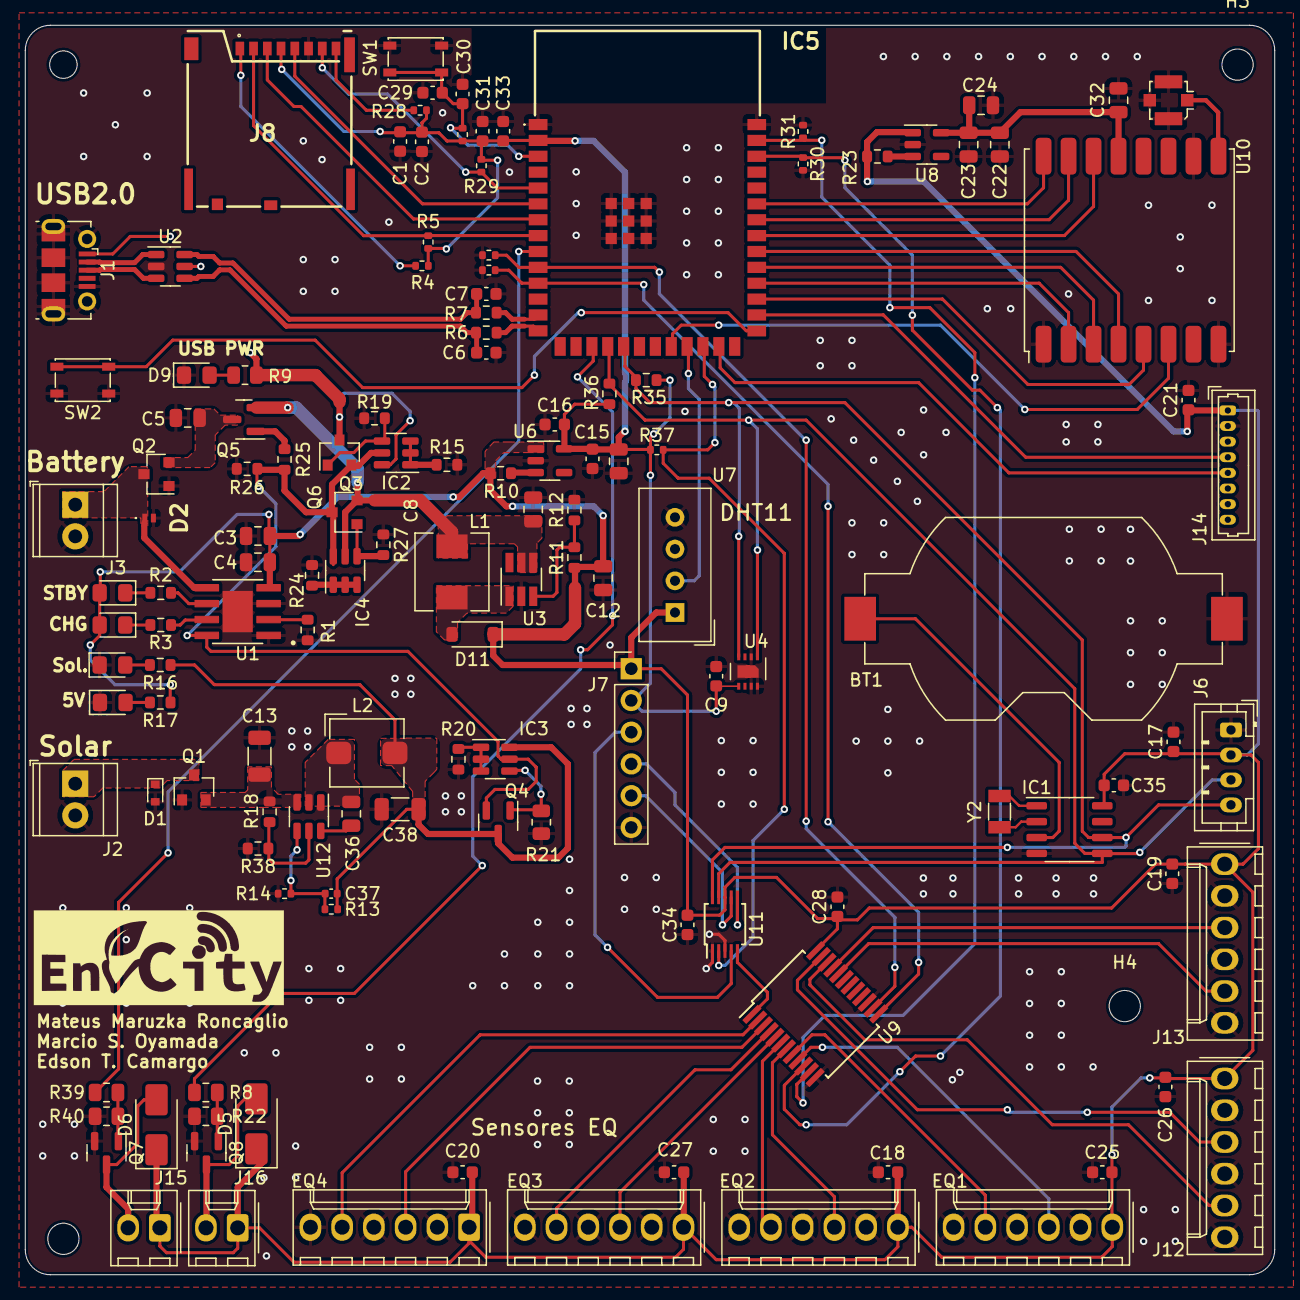
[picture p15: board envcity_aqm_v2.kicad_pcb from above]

Board: 2 copper layers, 100.0 x 100.0 mm, 136 parts (0 on the bottom side), 93 nets.

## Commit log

2022-01-13 Projeto da estação de monitoramento da qualidade do ar dividido em subprojetos. Cada subprojeto é um projeto independente do kicad.
    [ads1115_mux.kicad_pcb, ads1115_mux.sch, bq24160.kicad_pcb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]
2022-01-16 Conexão entre os componentes. Correção da lib do buck-boost. Separação do 3v3 da raspberry e do 3v3 do regulador
    [ads1115_mux.sch, envcity_pcb.sch, raspberry_pi4.sch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]
2022-01-17 Adicionando circuito para proteção de Vext_dc e Vusb; A explicação do circuito esta no esquematico
    [bq24160.sch, envcity_pcb.sch]
2022-01-17 Add proteção contra reversao de polaridade no conector da bateria
    [bq24160.sch, envcity_pcb.sch]
2022-01-17 Add pdf do esquemático. Add arquivo do kicad p/ a PCB.
    [envcity_pcb.kicad_pcb]
2022-01-20 Roteamento da PCB pronto; Agora o 3v3 da raspberry alimenta os resistores de pull up da comunicacao i2c do bq24160
    [bq24160.sch, envcity_pcb.kicad_pcb, envcity_pcb.sch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]
2022-01-25 Roteamento completo. Aprovado pelo professor Claudinei.
    [bq24160.sch, envcity_pcb.sch, rfm95w.sch]
2022-01-28 Add mounting holes. Corrige footprint dos conectores da bateria e alimentacao
    [bq24160.sch, envcity_pcb.kicad_pcb, envcity_pcb_BOM.csv]
2022-02-07 Add tear drops
    [envcity_pcb.kicad_pcb]
2023-01-31 new aqm board version
    [envcity_aqm_v2.kicad_pcb, envcity_aqm_v2.sch, envcity_aqm_v2_2layers.kicad_pcb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]
2023-02-01 Add placa com 4 camadas. Add dht11.
    [envcity_aqm_v2.sch, envcity_aqm_v2_2layers.kicad_pcb, envcity_aqm_v2_4layers.kicad_pcb]
2023-04-28 Changing USB conn and add esp32-c3-mini-wroom
    [envcity_aqm_v2-B_Cu.gbr, envcity_aqm_v2-B_Mask.gbr, envcity_aqm_v2-B_Paste.gbr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]
2023-04-28 add rfm95
    [envcity_aqm_v2.kicad_sch]
2023-04-29 Add conversor 3v3. Add rfm. Changing esp32c3-mini to esp32-s2
    [envcity_aqm_v2.kicad_sch]
2023-04-29 separa a alimentacao do esp32 e do rfm. add 2 conectores para alphasense. Add conector pms5003
    [envcity_aqm_v2.kicad_sch]
2023-05-02 Add um monte de coisa
    [envcity_aqm_v2.kicad_pcb, envcity_aqm_v2.kicad_sch]
2023-05-03 Add diversas trilhas e corrige 3dmodel
    [envcity_aqm_v2.kicad_pcb, envcity_aqm_v2.kicad_sch]
2023-05-03 circuito esp32 ok
    [envcity_aqm_v2.kicad_pcb, envcity_aqm_v2.kicad_sch]
2023-05-05 Alterando os indutores. Add diversos 3dmodel. Alterando cristal rtc. Refaz algumas trilhas
    [envcity_aqm_v2.kicad_pcb, envcity_aqm_v2.kicad_sch]
2023-05-06 Roteamento do cartao sd (incompleto). Roteamento USB com controle de impedancia ok.
    [envcity_aqm_v2.kicad_pcb, envcity_aqm_v2.kicad_sch]
2023-05-09 Terminando o posicionamento dos components
    [envcity_aqm_v2.kicad_pcb, envcity_aqm_v2.kicad_sch]
2023-05-10 mudando posicoes
    [envcity_aqm_v2.kicad_pcb, envcity_aqm_v2.kicad_sch]
2023-05-12 add 3dmodel cr2032 e algumas trilhas
    [envcity_aqm_v2.kicad_pcb]
2023-05-17 Alteracoes no roteamento
    [envcity_aqm_v2.kicad_pcb, envcity_aqm_v2.kicad_sch]
2023-05-19 add 3d model pms. add mais trilhas
    [envcity_aqm_v2.kicad_pcb, envcity_aqm_v2.kicad_sch]
2023-05-19 add trilhas
    [envcity_aqm_v2.kicad_pcb, envcity_aqm_v2.kicad_sch]
2023-05-24 Trocando o modelo do cartaoSD
    [envcity_aqm_v2.kicad_pcb, envcity_aqm_v2.kicad_sch]
2023-05-26 running DRC and fixing some errors
    [envcity_aqm_v2.kicad_pcb, envcity_aqm_v2.kicad_sch]
2023-05-29 Corrigindo LCSC part #
    [envcity_aqm_v2-B_Cu.gbr, envcity_aqm_v2-B_Mask.gbr, envcity_aqm_v2-B_Paste.gbr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]
2023-06-10 board ok. Add tps54202
    [envcity_aqm_v2.kicad_pcb, envcity_aqm_v2.kicad_sch]
2023-06-13 add novo conversor
    [envcity_aqm_v2.kicad_pcb, envcity_aqm_v2.kicad_sch]
2023-06-13 add gerber. corrige pcb
    [envcity_aqm_v2-B_Cu.gbr, envcity_aqm_v2-B_Mask.gbr, envcity_aqm_v2-B_Paste.gbr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]
2023-08-16 remove tranqueiras
    [envcity_aqm_v2.kicad_pcb]
2023-08-17 altera componentes
    [envcity_aqm_v2.kicad_pcb, envcity_aqm_v2.kicad_sch]
2023-08-26 Add logo na pcb
    Add a logo
    [envcity_aqm_v2.kicad_pcb, envcity_aqm_v2.kicad_sch]
2023-08-28 add novo esp32
    [envcity_aqm_v2.kicad_pcb, envcity_aqm_v2.kicad_sch]
2025-03-08 add sim
    [envcity_aqm_v2.kicad_sch]
2025-03-08 add flyback diode. add pulldown on fan switch fet
    [ads1115_mux.kicad_pcb, ads1115_mux.sch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]
2025-03-08 change simulations path
    [envcity_aqm_v2.sch]
